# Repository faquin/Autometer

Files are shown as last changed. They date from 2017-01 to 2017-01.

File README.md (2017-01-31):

#Autometer kitchen timer
## Presentation
This project started in India where I bought a rickshaw autometer. I got the idea of opening it and using its display somehow.
After some investigation of the current circuit, I replaced the orignial Atmega by an arduino micro.

I created a kitchen timer with it. It is working great:

1. At first, the Arduino is sleeping
2. When the back button is pressed, the Arduino wakes up and increment the number of minutes to count. The button can be pressed several times
3. When the handle is triggered, the countdown starts
4. When the countdown is 0, the buzzer activates until the handle is reset
5. Finally the Arduino goes back to sleep

## Files
### Autometer.ino
The Arduino code. It uses libraries
- RBD_Timer from http://robotsbigdata.com/docs-arduino-timer.html
- RBD_Button from http://robotsbigdata.com/docs-arduino-button.html
- SoftwareSerial from https://www.arduino.cc/en/Reference/softwareSerial
- TimerOne from http://playground.arduino.cc/Code/Timer1

### Autometer.fzz
The adaptater I had to make between the Atmega connector and the Arduino pins.

## Existing circuit
See the [dedicated page](docs/Analysisofexistingcircuit.pdf)

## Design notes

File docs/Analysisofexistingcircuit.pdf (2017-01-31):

Analysis of existing circuit

******************* TODO *********************
- Check what is the frequency update of each digit : use the core with resistor. Every sec, get the core to publish event with measured frequency
- Check what are the signals connected to the Atmega and how they are used
- See if it is possible to add a UART to the Atmega and replace it with Arduino chip
- Measure the voltage of one digit, see if it getting 5V or less. Can it be connected to 3.3v??
- Draw global schematic
- Write code see
http://www.electroschematics.com/10512/arduino-4-digit-7-segment-led-display/-

***********************************************
★ Power Input
- 12Vdc +/-25%
- Regulated with KA7805 on Power Supply Board 2
- 5V reach Display Board on CON1
★ Display Board
- Front
■ INPUT: information from the wheel, used to measure the KM ■ CON1: 5V+GND, see 1)
■ Buzzer is soldered
■ DP: External Push Button
■ MICRO: Switch activated by rotating the “For Hire” handle
■ ATMEL ATMEGA48PA-PU with quartz 4Mhz
■ It seems there is one I2C connector not soldered (maks SDA/SCL)
- Back
■ The numeric displayed are soldered directly on the back. They all have a comma, to see if it is connected
■ There are:
- One line with 5 big digits (E10561-G)
- One line with 4 big digits (E10561-G)
- One line with 4 small digits (E10391-G)
■ The displays are controlled by a chip 74HCT154N
■ There are 13 transistors CTBC 557B. These are NPN between the 74HCT154N and each digit http://www.farnell.com/datasheets/296678.pdf through a resitor
★ ATMEL ATMEGA48PA-PU chip
- Seems to be very low ram
- Using with Arduino
http://www.thinkcreate.org/index.php/arduino-porting-to-atmega48/

- Spec: http://www.atmel.com/images/doc8161.pdf
- Spec2:
http://www.atmel.com/images/Atmel-8271-8-bit-AVR-Microcontroller-ATmega48A-48PA-88A-88PA-168A-168PA-328-328P_datasheet_Complete.pdf (http://www.atmel.com/images/Atmel-8271-8-bit-AVR-Microcontroller-ATmega48A-48PA-88A-88PA-168A-168PA-328-328P_datasheet_Complete.pdf)
- Seems to be compatible with pin to pin with Arduino Atmega168 from Arduino duemilanove. See below

○
○

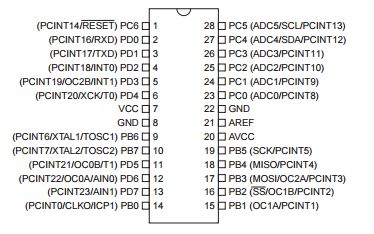
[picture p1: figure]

R18 - Vcc | 1 | 28 | R4 - segmF
Odometer Brown | 2 | 27 | R14 - segmE
(nothing) | 3 | 26 | R11 - segmD
74HCT pin 23 (A0) | 4 | 25 | R10 - segmC
74HCT pin 22 (A1) | 5 | 24 | R8 - segmB
74HCT pin 21 (A2) | 6 | 23 | R6 - segmA
Vcc | 7 | 22 | GND - R16 - Odometer Black
GND | 8 | 21 | Vcc
Quartz | 9 | 20 | Vcc - R18 - Odometer Red
Quartz | 10 | 19 | R27 - Transistor - Buzzer
74HCT pin 20 (A3) | 11 | 18 | R26 - DP external button
U1 pin 5 | 12 | 17 | (nothing)
U1 pin 6 | 13 | 16 | 74HCT pin 18+19 (EN)
RB25 - MICRO Handle | 14 | 15 | R3 - segmG

○
★ 74HCT154N chip
- Spec http://www.nxp.com/documents/data_sheet/74HC_HCT154.pdf
- This chip is a MUX 4->16
- It is probably used to enable individually each of the 13 digits
- Vcc min is 4.5V. Cannot work under 3.3V. However similar 74HC154N can... ★ E10xx1-G Digits
- Spec http://www.py2bbs.qsl.br/projetos/freq_dl4yhf/TOYO-E10561.pdf
- They are Code G, so common anode. So they are active at high level
- The pin 8 is connected to the output of the PNP transistor, which is coming from the mux. If the pin 8 is down, display is off.
- All digits of a row are using the digit selection signal. There are 7 signals commanded by resistors
■ First line of digits
Resistor | R3 | R4 | R6 | R8 | R10 | R11 | R14
Pin | 10 | 9 | 7 | 6 | 4 | 2 | 1
Segment | G | F | A | B | C | D | E

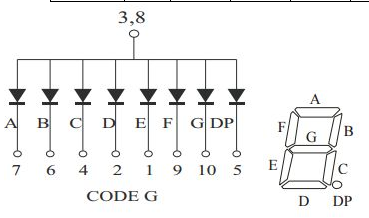
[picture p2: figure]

Note: pin 5 is not connected, this is the dot (DP). Also pin 3 is not connected

■ Second line of digits
- It seems the pins are connected to the same resistors as first line

■ Third line of digits

Resistor | R3 | R4 | R6 | R8 | R10 | R11 | R14
Pin | 1 | 2 | 10 | 9 | 7 | 5 | 4
Segment | G | F | A | B | C | D | E

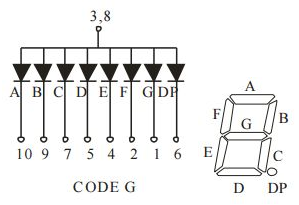
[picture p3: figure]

Note: pin 6 is not connected, this is the dot (DP). Also pin 3 is connected to pin 8
★ Digit activation
- The digits are activated through PNP which are controlled by the 74HCT154
Outpu t | Pin HCT | Resist or | Transi stor | Output | Pin HCT | Resist or | Transi stor
Y0 | 1 | R13 | Q5 | Y8 | 9 | R17 | Q9
Y1 | 2 | R5 | Q4 | Y9 | 10 | R21 | Q13
Y2 | 3 | R7 | Q3 | Y10 | 11 | R22 | Q12
Y3 | 4 | R9 | Q2 | Y11 | 13 | R23 | Q11
Y4 | 5 | R12 | Q1 | Y12 | 14 | R21 | Q10
Y5 | 6 | R15 | Q6 | Y13 | 15
Y6 | 7 | R20 | Q7 | Y14 | 16
Y7 | 8 | R19 | Q8 | Y15 | 17
- The digits are installed like following:
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
★ Using Arduino
- Switch to 4Mhz quartz
http://iot-playground.com/2-uncategorised/9-arduino-low-power-sensor
- Compatibility table:
PIN | ATMEGA48PA-PU PIN | ATMEGA 168 | Arduino | Compatible?
1 | R18 - Vcc | RESET | | OK
2 | Odometer Brown | PD0 | 0 | OK
3 | (nothing) | PD1 | 1 | OK
4 | 74HCT pin 23 (A0) | PD2 | 2 | OK
5 | 74HCT pin 22 (A1) | PD3 | 3 | OK
6 | 74HCT pin 21 (A2) | PD4 | 4 | OK
7 | Vcc | Vcc | | OK
8 | GND | GND | | OK
9 | Quartz | Quartz | | OK
10 | Quartz | Quartz | | OK
11 | 74HCT pin 20 (A3) | PD5 | 5 | OK
12 | U1 pin 5 | PD6 | 6 | OK
13 | U1 pin 6 | PD7 | 7 | OK
14 | RB25 - MICRO Handle | PB0 | 8 | OK
15 | R3 - segmG | PB1 | 9 | OK
16 | 74HCT pin 18+19 (EN) | PB2 | 10 | OK
17 | (nothing) | PB3 | 11 | OK
18 | R26 - DP external button | PB4 | 12 | OK
19 | R27 - Transistor - Buzzer | PB5 | 13 | OK
20 | Vcc - R18 - Odometer Red | Vcc | | OK
21 | Vcc | Vcc | | OK

22 | GND - R16 - Odometer Black | GND | | OK
23 | R6 - segmA | PC0 | A0(14)* | OK
24 | R8 - segmB | PC1 | A1(15)* | OK
25 | R10 - segmC | PC2 | A2(16)* | OK
26 | R11 - segmD | PC3 | A3(17)* | OK
27 | R14 - segmE | PC4 | A4(18)* | OK
28 | R4 - segmF | PC5 | A5(19)* | OK
*PortC is not named on the board, however it is named Ax in pins_arduino.h
★ Measuring 7segments refresh rate
- Method: by using Photon, measure the time between consecutive updates of one digit
- This can be done by measuring either:
■ when the signal EN to 74HCT is active. Assumption is that EN is toggled for every segment, which is not sure
■ when one particular 7segment is active: when it’s transistor is switched ON, and for how long
★ Buzzer connection
- The buzzer is controlled by Atmega pin 19 (PB5) through a PNP transistor 5578 (BC 557). The transistor base is connected to PB5 through R27 (2.2K), the base is also connected to Vcc through R28 (100K).
- When PB5 is 5V, buzzer is OFF
- When PB5 is 0V, buzzer is ON
- When Arduino is starting, PB5 is 0V, so buzzer is ON.
- => Arduino shall be reprogrammed so that the default status is 5V

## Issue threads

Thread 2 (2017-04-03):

Sometimes the buzzer triggers for a few ms when the handle is activated

faquin, 2017-04-03:

faquin, 2017-04-03:
Try to reset timer_countdown before going to sleep.
Or add digitalWrite(pinBuzzer, HIGH); in wakeUpNow ()

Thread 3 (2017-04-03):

Keeping the button pressed should increment the minutes

faquin, 2017-04-03:

faquin, 2017-04-03:
Check if something can be done with library http://robotsbigdata.com/docs-arduino-button.html#public-methods

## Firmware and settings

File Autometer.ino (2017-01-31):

#include <RBD_Timer.h>
#include <RBD_Button.h>
#include <SoftwareSerial.h>
#include <TimerOne.h>

#include <avr/sleep.h>

/*
  Version10 : Same as Version 6 for Arduino Micro.
  The user press the side button to increment a timer value. When the rotating handle is down, the counter starts to decrease.
  When it reaches 0, the buzzer activates until the roating handle is up again. This also shutdown the display.
*/

#define digitOFF 10

int pinA0 = A0;
int pinA1 = A1;
int pinA2 = A2;
int pinA3 = A4;
int pinSegmA = 7;
int pinSegmB = 8;
int pinSegmC = 9;
int pinSegmD = 10;
int pinSegmE = 11;
int pinSegmF = 12;
int pinSegmG = 1;
int pinEN = 0;
int pinButtonHandle = 4;
int pinButtonDP = 2;
int pinBuzzer = 3;

byte numbers[15][7] = {
  {0, 0, 0, 0, 0, 0, 1}, //zero
  {1, 0, 0, 1, 1, 1, 1}, //one
  {0, 0, 1, 0, 0, 1, 0}, //two
  {0, 0, 0, 0, 1, 1, 0}, //three
  {1, 0, 0, 1, 1, 0, 0}, //four
  {0, 1, 0, 0, 1, 0, 0}, //five
  {0, 1, 0, 0, 0, 0, 0}, //six
  {0, 0, 0, 1, 1, 1, 1}, //seven
  {0, 0, 0, 0, 0, 0, 0}, //eight
  {0, 0, 0, 0, 1, 0, 0}, //nine
  {1, 1, 1, 1, 1, 1, 1}, //off
  {0, 0, 0, 1, 0, 0, 0}, // A
  {0, 1, 1, 0, 0, 0, 1}, // C
  {0, 1, 1, 0, 0, 0, 0}, // E
  {0, 1, 1, 1, 0, 0, 0} // F
}; // manquent: H, L, n, o, P, U,

int DigitValue[13];
int isrActiveDigit = 0;
int count = 0;

int minutes = 0;
int secondes = 0;

//SoftwareSerial SerialParticle(A5, A4); // RX, TX

RBD::Button button_Handle(pinButtonHandle);
RBD::Button button_DP(pinButtonDP);

RBD::Timer timer_countdown(1000); // triggers every seconds // 250 for 4Mhz instead of 1000


void setDigitValue(int digit, int value) {
  // digit is from 0 to 12
  if (0 <= digit && digit < 13) {
    if (0 <= value && value < 15) {
      DigitValue[digit] = value;
    }
  }
}


void setDigitChar(int digit, char character) {
  // digit is from 0 to 12
  if (0 <= digit && digit < 13) {
    switch (character) {
      case 'A':
        DigitValue[digit] = 11;
        break;
      case 'C':
        DigitValue[digit] = 12;
        break;
      case 'E':
        DigitValue[digit] = 13;
        break;
      case 'F':
        DigitValue[digit] = 14;
        break;
    }
  }
}


void DigitOFF(int digit) {
  if (0 <= digit && digit < 13) {
    DigitValue[digit] = digitOFF;
  }
}

void setLineValue(int line, int digit1, int digit2, int digit3, int digit4, int digit5) {
  // line is 1 or 2 or 3
  if (line == 1) {
    setDigitValue(4, digit1);
    setDigitValue(3, digit2);
    setDigitValue(2, digit3);
    setDigitValue(1, digit4);
    setDigitValue(0, digit5);
  }
  else if (line == 2) {
    setDigitValue(8, digit1);
    setDigitValue(7, digit2);
    setDigitValue(6, digit3);
    setDigitValue(5, digit4);
  }
  else if (line == 3) {
    setDigitValue(12, digit1);
    setDigitValue(11, digit2);
    setDigitValue(10, digit3);
    setDigitValue(9, digit4);
  }
  
}

void setLineStr(int line, String strDigits) {
  // for line1, strDigit is 5 char (+1). For the other lines, StrDigit is 4 char (+1)
  int a, b, c, d, e;
  if (strDigits[0] == 32) // 32 is " " in ASCII
    a = digitOFF;
  else
    a = strDigits[0] - 48; //-48 because "0" is ASCII code 0x48

  if (strDigits[1] == 32)
    b = digitOFF;
  else
    b = strDigits[1] - 48;

  if (strDigits[2] == 32)
    c = digitOFF;
  else
    c = strDigits[2] - 48;

  if (strDigits[3] == 32)
    d = digitOFF;
  else
    d = strDigits[3] - 48;

  if (strDigits[4] == 32)
    e = digitOFF;
  else
    e = strDigits[4] - 48;

  setLineValue(line, a, b, c, d, e);
}

void wakeUpNow (void) {
  // do nothing: we are awake that's all!
}

void goToSleep() {
  setLineStr(1, "     ");
  setLineStr(2, "    ");
  setLineStr(3, "    ");
  delay(770);
  
  set_sleep_mode(SLEEP_MODE_PWR_DOWN);
  sleep_enable();
  attachInterrupt(digitalPinToInterrupt(pinButtonDP), wakeUpNow, LOW);
  sleep_mode();
  sleep_disable();         // first thing after waking from sleep:
  detachInterrupt(digitalPinToInterrupt(pinButtonDP));

}


void setup() {
  Serial.begin(9600);
  //SerialParticle.begin(9600);

  pinMode(pinA0, OUTPUT);  digitalWrite(pinA0, 0);
  pinMode(pinA1, OUTPUT);  digitalWrite(pinA1, 0);
  pinMode(pinA2, OUTPUT);  digitalWrite(pinA2, 0);
  pinMode(pinA3, OUTPUT);  digitalWrite(pinA3, 0);

  pinMode(pinSegmA, OUTPUT);
  pinMode(pinSegmB, OUTPUT);
  pinMode(pinSegmC, OUTPUT);
  pinMode(pinSegmD, OUTPUT);
  pinMode(pinSegmE, OUTPUT);
  pinMode(pinSegmF, OUTPUT);
  pinMode(pinSegmG, OUTPUT);

  pinMode(pinEN, OUTPUT);

  pinMode(pinBuzzer, OUTPUT);
  digitalWrite(pinBuzzer, HIGH); // switch off buzzer

  Timer1.initialize(770); // set a timer of length 770 microseconds (=100Hz/13 displays) // for 4Mhz quartz value is 192
  Timer1.attachInterrupt( isrUpdate7Seg ); // attach the service routine here

  setLineStr(1, "     ");
  setLineStr(2, "    ");
  setLineStr(3, "    ");

  //Serial.println("application starting v10.0");
  //delay(1000);


   goToSleep();
  
}

void loop() {


  if (button_Handle.onReleased()) {
    timer_countdown.stop();
    // setLineStr(1, " 0000"); useless since we are going to sleep just after
    minutes = 0;
    secondes = 0;
    goToSleep();

  }

  if (button_Handle.isReleased()) {
    if (button_DP.onPressed()) { // increment the counter at beginning
      if (minutes < 60) {
        minutes++;
        //secondes+=10; //debug
        setDigitValue(3, minutes / 10);
        setDigitValue(2, minutes % 10);
        setDigitValue(1, secondes / 10);
        setDigitValue(0, secondes % 10);
      }
    }
  }


  if (button_Handle.onPressed()) {
    timer_countdown.restart(); // launch the timer
  }

  if (button_Handle.isPressed()) {
    if (timer_countdown.onRestart()) {
      if (secondes > 0) {
        secondes--;
      }
      else {
        if (minutes > 0) {
          minutes--;
          secondes = 59;
        }
        else {
          timer_countdown.stop(); // countdown is expired
        }
      }


      setDigitValue(3, minutes / 10);
      setDigitValue(2, minutes % 10);
      setDigitValue(1, secondes / 10);
      setDigitValue(0, secondes % 10);

    }

    if (timer_countdown.isStopped()) { // as long as the countdown is stopped whilehandle is activated, buzzzz
      digitalWrite(pinBuzzer, LOW);
      delay(100);
      digitalWrite(pinBuzzer, HIGH);
      delay(3000); // let the buzzer stop
    }


  }


  /*Serial.print("min=");
  Serial.print(minutes);
  Serial.print(" sec=");
  Serial.println(secondes);
  */

}

/// --------------------------
/// Custom ISR Timer Routine
/// --------------------------
void isrUpdate7Seg()
{
  digitalWrite(pinEN, HIGH); // disable display during bits modifications

  isrActiveDigit = (isrActiveDigit + 1) % 13;
  digitalWrite(pinA0, bitRead(isrActiveDigit, 0));
  digitalWrite(pinA1, bitRead(isrActiveDigit, 1));
  digitalWrite(pinA2, bitRead(isrActiveDigit, 2));
  digitalWrite(pinA3, bitRead(isrActiveDigit, 3));

  digitalWrite(pinSegmA, numbers[DigitValue[isrActiveDigit]][0]);
  digitalWrite(pinSegmB, numbers[DigitValue[isrActiveDigit]][1]);
  digitalWrite(pinSegmC, numbers[DigitValue[isrActiveDigit]][2]);
  digitalWrite(pinSegmD, numbers[DigitValue[isrActiveDigit]][3]);
  digitalWrite(pinSegmE, numbers[DigitValue[isrActiveDigit]][4]);
  digitalWrite(pinSegmF, numbers[DigitValue[isrActiveDigit]][5]);
  digitalWrite(pinSegmG, numbers[DigitValue[isrActiveDigit]][6]);

  digitalWrite(pinEN, LOW); // enable display
}
